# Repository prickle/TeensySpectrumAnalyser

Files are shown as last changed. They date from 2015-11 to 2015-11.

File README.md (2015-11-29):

# Teensy Audio Spectrum Analyser
The Teensy Audio Spectrum Analyzer is a low-cost classic audio spectrum display with up to 128 bands.

Project details up on Hackaday
http://hackaday.io/project/8599

It displays a detailed picture of what you're hearing in real-time. It shows the changing spectrum of live input signals up to 16kHz.

It takes a mono analog RCA audio input (nominal 1v pp) and presents up to 128 bands of real-time colour spectrum display with peak metering.

You can easily observe the frequency characteristics of live music in real time. The spectral composition of acoustic signals become clearly visible.

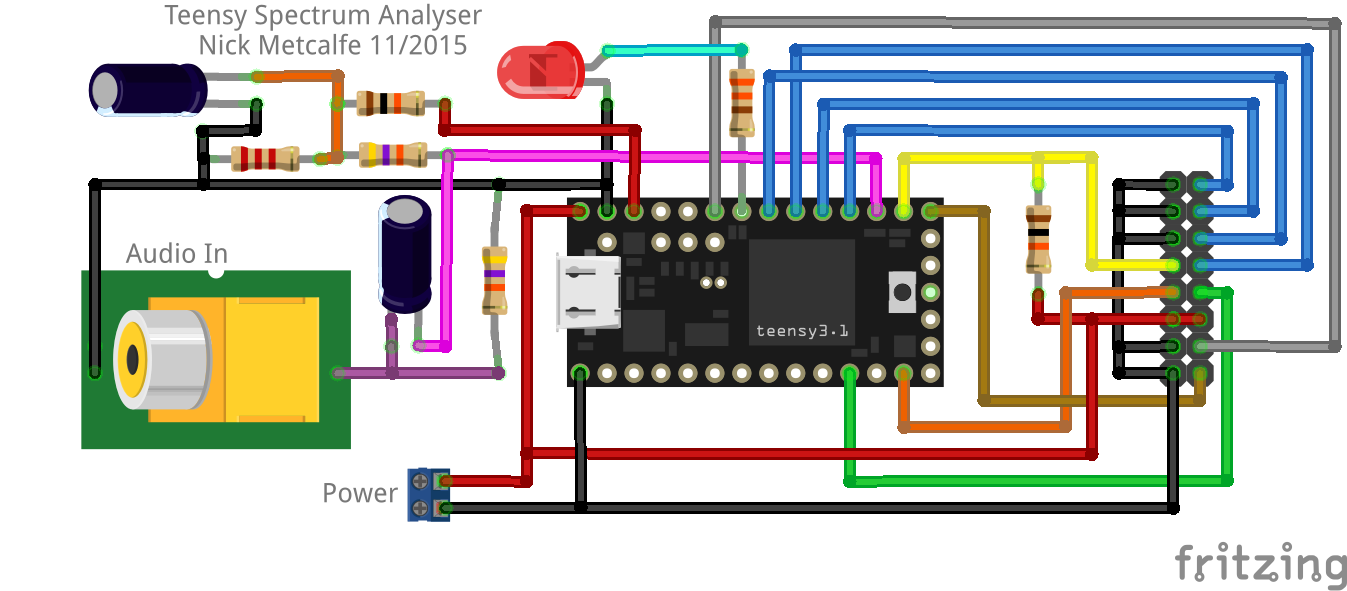
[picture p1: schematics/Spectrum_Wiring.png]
Wiring Diagram


----
The display is constructed using low-cost red/green LED matrix modules. These modules can be daisy-chained together to make larger displays. The prototype used two modules for a 64 band spectrum but up to four modules should work ok (untested).

16x32 DIY Kit Red Green Dual-Color Dot Matrix Control Display Module
http://www.ebay.com/itm/231503508955

The code intensity modulates the LEDs to minimise power consumption while still providing good visibility. It is just possible to power a unit with two display modules from USB only but it is recommended to provide an external power supply if more than two modules are used or the brightness is increased.

----
The controller can be a Teensy 3.1 or 3.2. 

The Teensy Audio Library is at the heart of the design, providing audio capture and high resolution FFT routines. Audio frequency data is scaled and binned into logarithmic frequency response groupings and is plotted using a custom fast display driver into a spectrum that approximates the human auditory response for a balanced visual aesthetic.

Teensy 3.2 controller
https://www.pjrc.com/store/teensy32.html

Teensy Audio Library
http://www.pjrc.com/teensy/td_libs_Audio.html

----
Audio Input

An RCA audio jack takes a mono line level signal (1v peak to peak) for input. A small amount of conditioning circuitry decouples the signal from the source and adds a DC bias to shift it into the analog to digital converter's range of sensitivity.

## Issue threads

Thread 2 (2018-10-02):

Wrong connection in schematics

Julius112, 2018-10-02:
Hi Nick,

First of all - thanks a lot for your amazing instructions.
It's been super useful for me build my own spectrum analyser. I use a WS2812B LED strip, which is cut in pieces and stuck together in a way that it builds a matrix. As the protocol of the WS2812B chips is extremely time sensitive and doesn't like interrupts, when writing data to the LEDs, I use an Arduino Pro Mini to handle the LED output. The Arduino is connected with the Teensy via i2c.
But that's actually not the issue...
I noticed that in the checked-in schematics there is a direct connection from the RCA pin to AGND of the Teensy board. Shouldn't there be a connection from RCA shell to AGND?
Please correct me if I'm wrong...however that was the only way I could get it to work.

Cheers,
Julius

prickle, 2018-10-03:
Hi Julius.
Thanks for your nice comments. That sounds like a clever setup you have going, I'm glad my simple setup helped you.

Now you mention it I realise the wiring diagram is a bit ambiguous. The black ground wire is meant for the outer RCA shell to AGND and the inner signal pin is for the purple wire to the bias resistor and decoupling capacitor just as you surmised.  For a proper schematic, look at the info for the ADC input component in the Teensy audio design tool. [http://www.pjrc.com/teensy/gui/](http://www.pjrc.com/teensy/gui/)

In fact it might work the other way round but not if you have a common system ground. It is a shame that the parts available in Fritzing are somewhat limited at the moment.

Glad you got it working! You can do so much more than I did with your RGB colour and brightness  control. I would love to see it!

Cheers,
Nick.

Julius112, 2018-10-03:
Hi Nick,

I'm pretty sure it would have been possible to do everything with the Teensy board only. However, due to my limited knowledge of interrupt handling on these boards I just used another microcontroller.

Being honest, I don't find the diagram from the GUI tool very useful as there is no mentioning of the audio ground (shell). That's why I used your diagram.

Anyway - happy to have it working now. I build the whole thing for a "portable" speaker system on a cart which we use for festivals on the campsite or on birthdays. As this thing is mostly focused on producing an unbearable amount of bass, I also had to manipulate the Teensys internal PDB to have a higher resolution on the bass frequencies. In the end it was enough to redefine a few compiler macros. I can send you a video, when the prototype is attached to the speaker, if you would like to see it.

Cheers,
Julius

prickle, 2018-10-04:
Hi Julius.

I think it what you have done sounds like the best way, I have used WS2812 and they don't play nice with timing. Check out [Mavpixel](https://github.com/prickle/Mavpixel) for an example. I had to break the strips into short lengths of eight pixels to get the interrupt rate high enough for full-speed serial.

I think some of the Teensy Neopixel libraries use DMA to lower interrupt overhead. But the Pro Mini is so cheap and cheerful and serve so well as glue logic or port extenders I often do the same as you and throw an extra processor or two in a project. My other go-to is a really super-cheap microcontroller purpose-designed for this kind of thing, the Texas Instruments [MSP-430](http://www.ti.com/tool/msp-exp430g2et) series chips. I have had good results with these and you can get them in DIP packages and code them Arduino-style using Energia.

I would love to see a video! Great work! Looking forward to your project's completion.

Cheers,
Nick.

Closed 2018-10-03.

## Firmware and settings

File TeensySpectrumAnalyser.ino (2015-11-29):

/* 
Led matrix array Spectrum Analyser
22/11/2015 Nick Metcalfe

Takes a mono analog RCA audio input (nominal 1v pp) and presents a 64-band
real-time colour spectrum analyser display with peak metering.

Using two of:
16x32 DIY Kit Red Green Dual-Color Dot Matrix Control Display Module
http://www.ebay.com/itm/231503508955

Built with Teensy 3.2 controller
https://www.pjrc.com/store/teensy32.html
and the Teensy Audio Library
http://www.pjrc.com/teensy/td_libs_Audio.html

Portions of code based on:

myMatrix – Arduino library for LED matrix panels
Copyright (c) 2015 Silviu - www.openhardware.ro
http://openhardware.ro/mymatrix/

CShiftPWM.cpp - ShiftPWM.h - Library for Arduino to PWM many outputs using shift registers
Copyright (c) 2011-2012 Elco Jacobs, www.elcojacobs.com
https://www.pjrc.com/teensy/td_libs_ShiftPWM.html

Logarithmic band calculations
http://code.compartmental.net/2007/03/21/fft-averages/


Copyright (c) 2015 Nick Metcalfe  valves@alphalink.com.au
All right reserved.

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
You should have received a copy of the GNU Lesser General Public
License along with this library; if not, write to the Free Software
Foundation, Inc., 51 Franklin St, Fifth Floor, Boston, MA  02110-1301  USA
*/

#include <Audio.h>
#include <Wire.h>
#include <SPI.h>
#include <SD.h>
#include <SerialFlash.h>
#include <time.h>       /* time_t, struct tm, time, mktime */
#include "font5x7.h"

//Note: -- Use 96Mhz CPU Speed --

//Hardware setup
//These can be on any unused pin
const int m_latchPin = 21;
const int m_redPin = 11;
const int m_greenPin = 9;
const int m_clockPin = 13;
const int m_enablePin = 14;
const int m_ledPin = 20;

//Row drivers need to stay on these pins as they are used with 
//direct port access on GPIOB
const int m_aPin = 16;
const int m_bPin = 17;
const int m_cPin = 19;
const int m_dPin = 18;


//This should be changed to suit the installation.
//Should go up to four panels.
const unsigned char m_amountOfPanels = 2;      //Number of panels in this installation

//Screen refresh parameters
//At 800 hz line refresh rate, given we must push 16 rows of
//up to 128 pixels per line, the frame rate should be 50hz.
//At this speed, we can manage about 8 PWM brightness steps
//before using large quantities of CPU time.
const int m_ledFrequency = 800;                //Row refresh speed 800/16 rows = 50hz frame rate
const unsigned char m_maxBrightness = 8;       //PWM steps from dim to full brightness

//Default brightness of red and green used for all current graphics.
//Note: increasing these will increase current consumption. Take care if powering from USB.
const int m_redIntensity = 1;
const int m_greenIntensity = 4;                //green is dimmer

//Changing the gain changes the overall height of the bars in the display 
//by a proportionate amount. Note that increasing the gain for low-level 
//signals also increases background noise to a point where it may start to 
//show along the bottom of the display. m_shift can hide this.
const float m_gain = 240.0;                       //Input gain

//Shifts the bars down to conceal the zero-point as well as any additional 
//background noise. If random data shows at the very bottom of the display 
//when no input is present, increase this value by steps of 0.1 to just past 
//the point where it disappears. This should be 0.1 in a good quiet design.
const float m_shift = 1.0;                       //Shift bars down to mask background noise

//Controls how fast each spectrum bar shrinks back down. Larger numbers are faster.
const float m_decay = 1.0;                      //Speed of band decay

//Enable showing the red peak trace. Turn it off for a pure spectrum display.
const bool m_showPeak = true;                    //Show peaks

//How many 20ms cycles the peak line holds on the display before resetting. As the
//peak timer is restarted by peaks being nudged up, this should remain short or 
//the peak display tends to get stuck.
const int m_peakCounter = 5;

//How many pixels of spectrum need to show on the display for the peak line to appear.
//This hides the peak when no input is present in order to blank and save the display.
const int m_peakDisplayThreshold = 12;           //Minimum number of pixels under peak for it to show

//The noise gate mutes the input when the peak is below m_peakDisplayThreshold. This
//can be used to conceal narrow band background noise.
const bool m_noiseGate = true;

//Spectrum bar colour controls. These are pixel heights starting with zero at the bottom.
const int m_orangeSection = 10;                  //Height at which band bar turns orange
const int m_redSection = 14;                     //Height at which band bar turns red

//Shape of spread of frequency steps within the passband. Shifts the middle part left
//or right for visual balance. 0.05 for a hard logarithmic response curve to 0.40 for 
//a much more linear curve on two displays.
const float logScale = 0.14;  //Scale the logarithm curve deeper or shallower

//Enable the GPS clock.
//Comment out this whole line if no GPS is connected.
//#define ENABLE_GPSCLOCK

#ifdef ENABLE_GPSCLOCK
//GPS baud rate.
const int m_gpsBaud = 115200;

//Delay in 20ms ticks after peak disappears before GPS clock appears.
const int m_gpsDelay = 100;                   //2 seconds

//Time zone offset.
const int m_timeZone = +11;

#endif

//Uncomment this line to use a serial terminal (57600 baud) to see debugging
//messages.
//#define SERIAL_DEBUG

//-----------------------------------------------------------------------------------------------
// Shouldn't need to change stuff below here

//Screen size constants
const int m_amountOfRows = 16;                 //Number of rows
const int m_bankRegisters = 4;                 //4 registers per panel
const int m_bankOutputs = m_bankRegisters * 8; //Ouputs per panel
const unsigned char m_amountOfRegisters = m_amountOfPanels * m_bankRegisters; //Number of shift registers per row
const int m_amountOfColumns = m_amountOfRegisters * 8;  //Number of outputs per row
const int m_bufferSize=m_amountOfColumns * m_amountOfRows;  //Total size of single colour buffer

//Colour buffers are arranged as two buffers, one for each colour. These are laid out
//as linear frame buffer arrays with each byte corresponding to the pixel's brightness.
unsigned char * m_redPWMValues;
unsigned char * m_greenPWMValues;

//ISR variables
volatile unsigned char m_counter;                //PWM counter
unsigned char m_currentRow;                      //Displayed row
unsigned int m_rowOffset;                        //Offset into buffer for current row

//FFT display
bool m_refreshScreen = false;                    //Flag to completely redraw screen
unsigned int logGen1024[m_amountOfColumns][2] = {0}; //Linear1024 -> Log64 mapping
unsigned char m_bands[m_amountOfColumns] = {0};  //band pixel height
float m_bandVal[m_amountOfColumns] = {0.0};      //band FP value
const unsigned int logAmpSteps = 64;             //How many steps in the log amp converter
int logAmpOffset[logAmpSteps] = {0};             //Linear64 -> Log16 mapping

//Peak display
unsigned char m_peaks[m_amountOfColumns] = {0};  //peak pixel height
float m_peakVal[m_amountOfColumns] = {0.0};      //peak FP value

//GPS clock
#ifdef ENABLE_GPSCLOCK
bool m_gpsLock = false;                  //If the GPS has a lock
bool m_clockShowing = false;             //If the click is currently on screen
int gpsCounter = 0;                      //GPS display timeout counter
time_t m_currentTime = 0;                //current time
#endif

//Scrolling controls
bool scrolling = false;                  //If we are currently scrolling
int scrollPos = 0;                       //Current scrolling horizontal position offset
char *scrollString;                      //Pointer to current text string
uint8_t scrollY = 0;                     //Vertical position offset
uint8_t scrollFor = 0;                   //Text foreground colour
uint8_t scrollBk = 0;                    //Text background colour
const int scrollSpeed = 2;               //Scrolling speed in 20ms increments


// GUItool: begin automatically generated code
AudioInputAnalog         adc1(A1);        //xy=144,119
AudioAnalyzeFFT1024      fft1024_1;       //xy=498,64
AudioConnection          patchCord1(adc1, fft1024_1);
// GUItool: end automatically generated code

//-------------------------------------------------------------------------------------------------

// the setup() method runs once, when the sketch starts

void setup() {
  initDisplay();
  pinMode(m_ledPin, OUTPUT);
  AudioMemory(8);
#ifdef ENABLE_GPSCLOCK
  Serial1.begin(m_gpsBaud);
#endif
#ifdef SERIAL_DEBUG
  delay(1000);
  Serial.begin(57600);
#endif
  calcBands();
  calcAmplitudes();
  //Intro string
  hScroll(3, 1, 0, "Teensy Audio Spectrum Analyzer");// - v1.0 : Nick Metcalfe : 21/11/2015");
}  

// the loop() method runs over and over again,
// as long as the board has power

void loop() {
  static int peakCount = 0;      //Peak delay counter
  int barValue, barPeak;         //current values for bar and peak
  float maxPeak = 0;             //Sum of all peak values in frame
  static bool drawPeak = true;   //Show peak on display
  if (fft1024_1.available()) {
    if (m_refreshScreen) SetAll(0);
    for (int band = 0; band < m_amountOfColumns; band++) {
      //Get FFT data
      float fval = fft1024_1.read(logGen1024[band][0], logGen1024[band][1]);
      fval = fval * m_gain - m_shift;
      if (fval > logAmpSteps) fval = logAmpSteps;            //don't saturate the band

      //process bands bar value
      if (m_bandVal[band] > 0) m_bandVal[band] -= m_decay;   //decay current band
      if ((drawPeak || !m_noiseGate) && fval > m_bandVal[band]) m_bandVal[band] = fval; //set to current value if it's greater
      barValue = (int)m_bandVal[band];                       //reduce to a pixel location
      if (barValue > logAmpSteps - 1) barValue = logAmpSteps - 1; //apply limits
      if (barValue < 0) barValue = 0;
      barValue = logAmpOffset[barValue];

      //process peak bar value
      if (drawPeak || !m_noiseGate) fval = m_bandVal[band] + 0.1; //examine band data transposed slightly higher
      else fval += 0.1;
      if (fval > m_peakVal[band]) {                //if value is greater than stored data
        m_peakVal[band] = fval;                    //update stored data
        peakCount = m_peakCounter;                 //Start the peak display counter
      }
      barPeak = (int)m_peakVal[band];              //extract the pixel location of peak
      if (barPeak > logAmpSteps - 1) barPeak = logAmpSteps - 1; //apply limits
      if (barPeak < 0.0) barPeak = 0.0;
      barPeak = logAmpOffset[barPeak];
      maxPeak += barPeak;                          //sum up all the peaks
      
      //Erase previous band bar
      if (m_bands[band] <= barValue) {             //if current band bar is lower than previous
        setGreenPixel(band, m_bands[band], 0);     //erase pixel above
        setRedPixel(band, m_bands[band], 0);
      }
      //Erase previous peak
      if (m_showPeak && m_peaks[band] >= 0) setRedPixel(band, m_peaks[band], 0);
      
      //Draw new band bar. If scrolling, draw the whole bar. If not, draw just the new portion
      if (scrolling || m_refreshScreen || (barValue >= 0 && barValue > m_bands[band])) {
        int barBase;
        if (scrolling || m_refreshScreen) barBase = 0; //if scrolling, draw the whole bar
        else barBase = m_bands[band];               //else draw just the portion at the top
        if (barBase < 0) barBase = 0;
        //Bar drawing loop
        for (int i = barBase; i < barValue; i++) {
          if (i < m_redSection)                     //Less than red section always draws green
            setGreenPixel(band, i, m_greenIntensity);
          if (i >= m_orangeSection)                 //Above orange section always draws red
            setRedPixel(band, i, m_redIntensity);
        }
      }
      
      //Draw peak point
      int peakIntensity = (peakCount > 0) * m_redIntensity;//peakCount / 8 + 1;  //Peak intensity modulation disabled
      if (m_showPeak && drawPeak && peakCount > 0) setRedPixel(band, barPeak, peakIntensity);
      
      //Update pixel value trackers
      m_bands[band] = barValue;
      m_peaks[band] = barPeak;
    }
    m_refreshScreen = false;
    //Detect peak threshold - more than so many pixels under the peaks for it to show, and lingers until counter expires
    drawPeak = (maxPeak > m_peakDisplayThreshold && peakCount > 0);
    
    //Peak counter timeout
    if (peakCount > 0) {                                      //if the peak conter is active
      if (--peakCount == 0) {                                 //and decrementing it deactivates it
        for (int band = 0; band < m_amountOfColumns; band++) {  //clear the peak values
          m_peakVal[band] = 0;
        }
      }
    }

#ifdef ENABLE_GPSCLOCK
    handleGps();                                //Parse any incoming GPS messages
    //GPS display timeout counter - GPS clock delay after peaks disappear
    if (drawPeak) {                             //No clock if peaks are drawing
      gpsCounter = 0;                           //Reset the GPS display timeout counter
      if (m_clockShowing) {                     //if the clock was onscreen
        m_refreshScreen = true;                 //Redraw the screen
        m_clockShowing = false;                 //clock is no longer showing
      }
    }    
    if (gpsCounter < m_gpsDelay) gpsCounter++;  //increment the GPS display timeout counter
    //Draw the GPS clock    
    else drawGpsClock();                        //Timed out - draw the clock
#endif

  }
  //Manage the text scrolling
  hScrollStep();
  //Loop delay for about 50cps screen refresh
  delay(20);
}

//-------------------------------------------------------------------------------------------------
// ISR display handler

static IntervalTimer itimer;
//Initialise and start ISR timer
void InitTimer(void){
	itimer.begin(ShiftPWM_handleInterrupt,
	  1000000.0 / (m_ledFrequency * (m_maxBrightness+1)));
}

//Set the row output demultiplexers (2 x 74xx138)
// Optimised for pins 16, 17, 19, 18 as bits 0,1,2,3 of row
// See https://forum.pjrc.com/threads/17532-Tutorial-on-digital-I-O-ATMega-PIN-PORT-DDR-D-B-registers-vs-ARM-GPIO_PDIR-_PDOR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
static inline void setRow(unsigned char row){
  GPIOB_PDOR = row & 0x0F;
}

//Fast inline function to present two-line serial RG data and perform one clock toggle
static inline void pwm_output_one_pin(const unsigned char counter, unsigned char * redPtr, unsigned char * greenPtr){
    digitalWriteFast(m_clockPin, LOW);
    digitalWriteFast(m_redPin, *(redPtr)<=counter );
    digitalWriteFast(m_greenPin, *(greenPtr)<=counter );
    digitalWriteFast(m_clockPin, HIGH);
}

//Main timer ISR
//We shift out a single line during the interrupt. The display has each bank of 
//32 outputs reversed, hence the funny pointer arithmetic
void ShiftPWM_handleInterrupt(void){
  unsigned char *redPtr = 0, *greenPtr = 0;
  int bankOffset = m_amountOfColumns;                      //Start past the last bank
 
  // Write shift register latch clock low 
  digitalWriteFast(m_latchPin, LOW);
  
  //Use port manipulation to send out all bits
  for(unsigned char i = 0; i < m_amountOfRegisters; i++){  // do one shift register at a time. This unrolls the loop for extra speed
    //Check for bank border
    if (i % m_bankRegisters == 0) {                        //edge of a bank?
      bankOffset -= m_bankOutputs;                         //skip backwards through banks
      redPtr=&m_redPWMValues[m_rowOffset + bankOffset];    //reset pointers to previous bank
      greenPtr=&m_greenPWMValues[m_rowOffset + bankOffset];
    }
    //Shift out 8 values for one register
    pwm_output_one_pin(m_counter, redPtr++, greenPtr++);  // This takes 12 or 13 clockcycles
    pwm_output_one_pin(m_counter, redPtr++, greenPtr++);
    pwm_output_one_pin(m_counter, redPtr++, greenPtr++);
    pwm_output_one_pin(m_counter, redPtr++, greenPtr++);
    pwm_output_one_pin(m_counter, redPtr++, greenPtr++);
    pwm_output_one_pin(m_counter, redPtr++, greenPtr++);
    pwm_output_one_pin(m_counter, redPtr++, greenPtr++);
    pwm_output_one_pin(m_counter, redPtr++, greenPtr++);
  }

  // Write shift register latch clock high
  digitalWriteFast(m_latchPin, HIGH);

  //Cycle through the PWM counter on each line and switch to next row when counter expires
  if(m_counter < m_maxBrightness){
    m_counter++;                       // Increase the counter for this row
  } else {                             // Row finished..
    m_counter=0;                       // Reset counter if it maximum brightness has been reached
    m_rowOffset += m_amountOfColumns;  // Move the pointer offset to next row
    if (++m_currentRow >= m_amountOfRows) {  //Just did last row?
      m_currentRow = 0;                //start again from the beginning
      m_rowOffset = 0;
    }
    setRow(m_currentRow);              //Switch display to new row
  }
}

//----------------------------------------------------------------------------------------------
// Display routines

void initDisplay() {
  //Reset variables
  m_counter = 0;
  m_redPWMValues = 0;
  m_greenPWMValues = 0;
  m_currentRow = 0;
  m_rowOffset = 0;  
  // initialize the digital pins.
  pinMode(m_enablePin, OUTPUT);
  digitalWrite(m_enablePin, LOW);
  pinMode(m_redPin, OUTPUT);
  pinMode(m_greenPin, OUTPUT);
  pinMode(m_clockPin, OUTPUT);
  pinMode(m_latchPin, OUTPUT);
  pinMode(m_aPin, OUTPUT);
  pinMode(m_bPin, OUTPUT);
  pinMode(m_cPin, OUTPUT);
  pinMode(m_dPin, OUTPUT);
  setRow(0);
  digitalWrite(m_clockPin, LOW);
  digitalWrite(m_redPin, LOW);
  digitalWrite(m_greenPin, LOW);
  //Allocate buffer memory
  AllocateBuffers();
  //Start timer
  InitTimer();
}

//Allocate and clear frame buffer memory
void AllocateBuffers(){
  cli(); // Disable interrupt
  m_redPWMValues = (unsigned char *) malloc(m_bufferSize); //resize array for PWMValues
  m_greenPWMValues = (unsigned char *) malloc(m_bufferSize); //resize array for PWMValues
  if (m_redPWMValues > 0 && m_greenPWMValues > 0) {
    SetAll(0);
  } else {
    Serial.println(F("Out of memory in SetAmountOfRegisters()"));
    //while(1){}
  }
  sei(); //Re-enable interrupt
}

//Fill frame buffer with fixed values
void SetAll(unsigned char red, unsigned char green){
  for(int k=0 ; k<(m_bufferSize);k++){
    m_redPWMValues[k]=red;
    m_greenPWMValues[k]=green;
  }
}
void SetAll(unsigned char value){
  SetAll(value, value);
}

//Red-only pixel routines, bottom-left coordinate system for FFT graphics
void setRedPixel(uint16_t x ,uint8_t y, uint8_t red)
{
  unsigned int address = ((m_amountOfRows - 1) - y) * m_amountOfColumns + x;
  if (address >= 0 && address < m_bufferSize)
    m_redPWMValues[address]=red;
}

//Green-only pixel routines, bottom-left coordinate system for FFT graphics
void setGreenPixel(uint16_t x ,uint8_t y, uint8_t green)
{
  unsigned int address = ((m_amountOfRows - 1) - y) * m_amountOfColumns + x;
  if (address >= 0 && address < m_bufferSize)
    m_greenPWMValues[address]=green;
}

//Base graphic pixel routine, top-left coordinate system for text
// Full-colour version
void setPixel(uint16_t x ,uint8_t y, uint8_t red, uint8_t green)
{
  unsigned int address = y * m_amountOfColumns + x;
  if (address >= 0 && address < m_bufferSize)
  {
    m_greenPWMValues[address]=green;
    m_redPWMValues[address]=red;
  }
}

//Base graphic pixel routine, top-left coordinate system for text
// limited bit-colour version using default intensities
void setPixel(uint16_t x ,uint8_t y, uint8_t colour) //color 2 Bit, (R)ed (G)reen 0b000000RG
{
  setPixel(x ,y, ((colour&0x02)>0)*m_redIntensity, (colour&0x01)*m_greenIntensity);
}

//Print a character
void printChar(uint16_t x,uint8_t y, uint8_t For_color, uint8_t Bk_color, char ch)
{
  uint16_t xx,yy,offset;
  xx=0;
  yy=0;
  offset=0;
  ch = ch-32;
  for (yy=0; yy < 7; yy++)
  {
    for (xx=0; xx < 5; xx++)
    {
      if (bitRead(pgm_read_byte(&font5x7[ch][yy]),4-xx)) // 4 == Font witdh -1
      {
        setPixel(x+xx,y+yy,For_color);
      }
      else
      {
        setPixel(x+xx,y+yy,Bk_color);
      }
    }
  }
}

//Print a whole string
void printString(uint16_t x, uint8_t y, uint8_t For_color, uint8_t Bk_color,char *p)
{   
   while(*p!='\0')
   {
     printChar(x,y,For_color,Bk_color,*p);
     x+=6; // 6 = font width + 1 pixel space
     p++;
   }
}

//Scroll a string over the display in the background
void hScroll(uint8_t y, uint8_t For_color, uint8_t Bk_color,char *mystring) 
{
  scrollString = mystring;
  scrollPos = -(m_amountOfColumns) - 1;
  scrollY= y;
  scrollFor = For_color;
  scrollBk = Bk_color;
  scrolling = true;
}

//Manage any scrolling text
//called periodically from loop()
void hScrollStep()
{
  static int div = 0;
  if (!scrolling) return;
  if (div++ < scrollSpeed) {
    return;
  }
  div = 0;
  int offset = scrollPos;
  int strLen = lenString(scrollString)*6;
  for (int xx=0; xx<m_amountOfColumns; xx++)
  {
    for (int yy=0; yy<7; yy++)
    {
      int c;
      if (getPixelHString(xx+offset,yy,scrollString)) c = scrollFor; else c = scrollBk;
      if (xx+offset >= 0 && xx+offset <= strLen-1) setPixel(xx,yy+scrollY,c);
    }
  }
  if (scrollPos++ == strLen) {
    scrolling = false;
  }
}

//Find the character length of a C string
unsigned int lenString(char *p)
{
  unsigned int retVal=0;
  while(*p!='\0')
  { 
   retVal++;
   p++;
  }
  return retVal;
}

//Get a pixel from a particular character in the font map
byte getPixelChar(uint8_t x, uint8_t y, char ch)
{
   ch = ch-32;
   if (x > 4) return 0; // 4 = font Width -1
   return bitRead(pgm_read_byte(&font5x7[ch][y]),4-x); // 4 = Font witdh -1  
}

//Get a pixel from a coordinate in a font-mapped string
byte getPixelHString(uint16_t x, uint16_t y, char *p)
{
   if (x < 0) return 0;
   p=p+x/6;
   return getPixelChar(x%6,y,*p);
}
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

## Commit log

2015-11-29 First commit of code
    [Spectrum.fzz]
2015-11-29 Update filename for Arduino
